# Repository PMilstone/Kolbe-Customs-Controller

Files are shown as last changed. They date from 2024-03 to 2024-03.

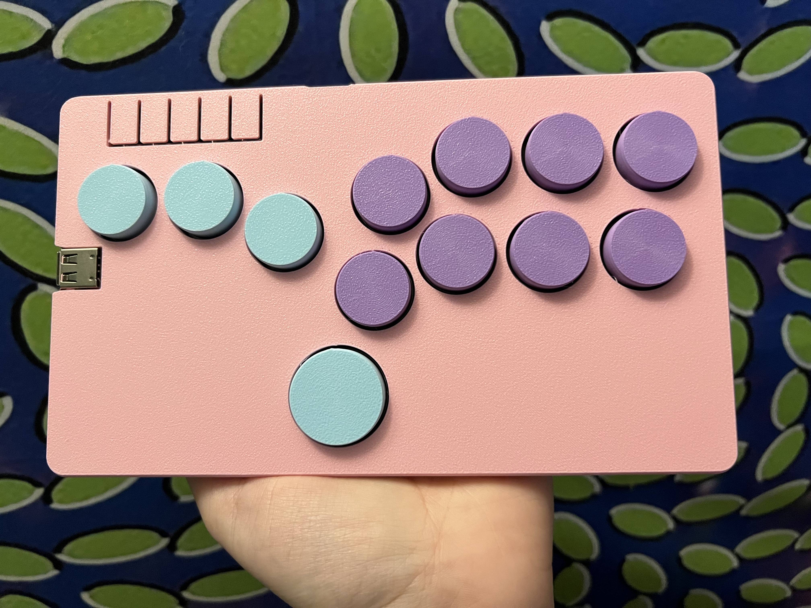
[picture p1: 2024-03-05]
Pictures/IMG_5434.jpg

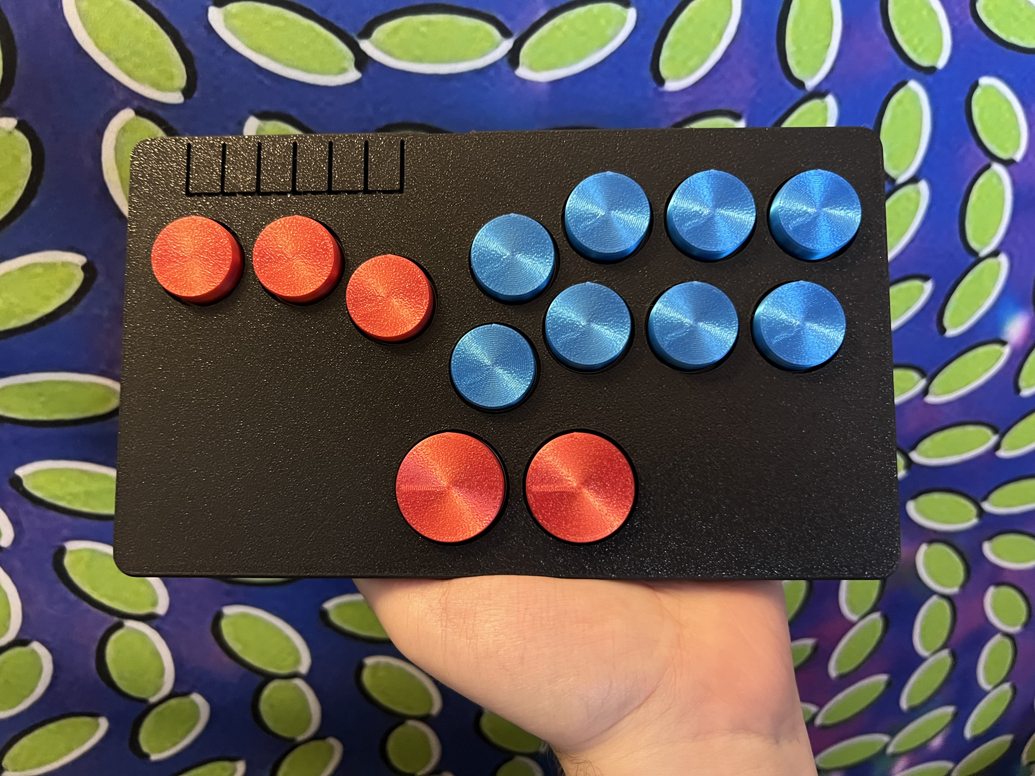
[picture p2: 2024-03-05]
Pictures/IMG_5296.jpg

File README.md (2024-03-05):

# Kolbe Customs Controller

This project is a remix of the Flatbox rev5 by jfedor2 here: https://github.com/jfedor2/flatbox/tree/master/hardware-rev5. The changes made are the following:

- Shadow lines to make a cleaner seam
- Use of M3 heat inserts
- Compatibility with Choc v2 switches

This project requires the following:

- [3D printed](3d-models) top and bottom case, 11 24mm buttons, and 1 or 2 30mm buttons
- The [PCB](pcb), with or without the USB passthrough assembely
- [RP2040-Zero](https://www.waveshare.com/rp2040-zero.htm)
- 6x [6x6x5mm tactile switches](https://www.amazon.com/gp/product/B01CGMP9GY/ref=ppx_yo_dt_b_search_asin_title?ie=UTF8&psc=1) (these come on the PCB if you buy it preassembled via jlpcb)
- Optional [USB port](https://www.mouser.com/ProductDetail/640-USB1046GF0190LBA) if using USB passthrough for Xbox S|X or PS5
- 12 or 13 [Kailh low profile (choc v2) switches](https://mechanicalkeyboards.com/shop/index.php?l=product_detail&p=6341) of your choice
- 12 or 13 [Kailh low profile hotswap sockets](https://mechanicalkeyboards.com/shop/index.php?l=product_detail&p=6995)
- 7x [M3 3.8mm heat set inserts](https://www.mcmaster.com/94180A331)
- 7x [M3 8mm Screws](https://www.mcmaster.com/91294A128) and wrench
- \(Optional)Right angle USB-C cable

Included in the 3D Models folder, there are 4 case tops. You will choose the coresponding top for if you want 2 thumb buttons, USB passthrough, or both. All options use the same bottom case.

I print my cases and buttons 0.3mm layer height with a 0.6mm nozzle.

To flash the firmware, connect the board to a computer with a USB cable, then press the RESET button while holding the BOOT button on the RP2040-Zero. A drive named "RPI-RP2" should appear. Copy the UF2 file you downloaded to that drive.

PCB design licensed under [CC BY-SA 4.0](https://creativecommons.org/licenses/by-sa/4.0/).

PCB design uses the following:

- [remix of jfedor2's flatbox rev5](https://github.com/jfedor2/flatbox/tree/master/hardware-rev5)
- [keyswitches.pretty](https://github.com/daprice/keyswitches.pretty) by [daprice](https://github.com/daprice) ([CC BY-SA 4.0](https://creativecommons.org/licenses/by-sa/4.0/))
- RP2040-Zero STEP file downloaded from [Waveshare wiki](https://www.waveshare.com/wiki/RP2040-Zero)

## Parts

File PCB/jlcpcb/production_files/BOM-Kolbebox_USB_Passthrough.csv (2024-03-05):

Comment | Designator | Footprint | LCSC
SW_Push | SW26 | SW_PUSH_6mm_H5mm
SW_Push | SW14 | SW_PUSH_6mm_H5mm
SW_Push | SW27 | SW_PUSH_6mm_H5mm
SW_Push | SW13 | SW_PUSH_6mm_H5mm
SW_Push | SW15 | SW_PUSH_6mm_H5mm
SW_Push | SW28 | SW_PUSH_6mm_H5mm
RP2040-Zero | A1 | RP2040-Zero
Fuse | F1 | Fuse_0805_2012Metric
Resistor 2 | Re2 | R_0603_1608Metric
Resistor 1 | Re1 | R_0603_1608Metric

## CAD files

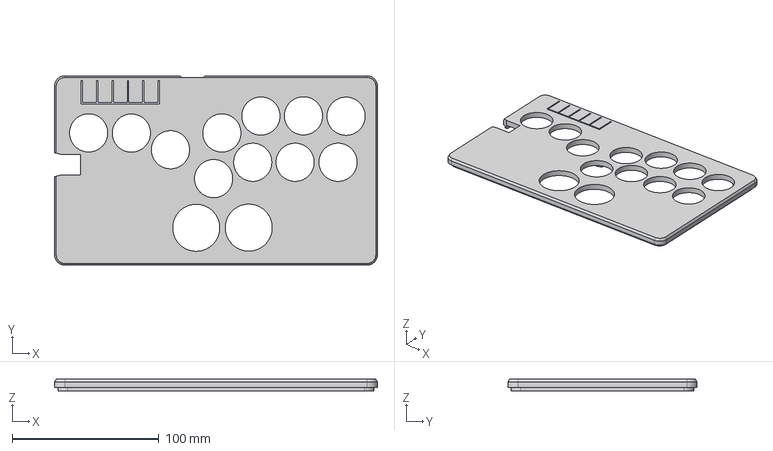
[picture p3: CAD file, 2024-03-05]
3D Models/USB Top 2 Thumb.step
219.8 x 128.7 x 8.10 mm

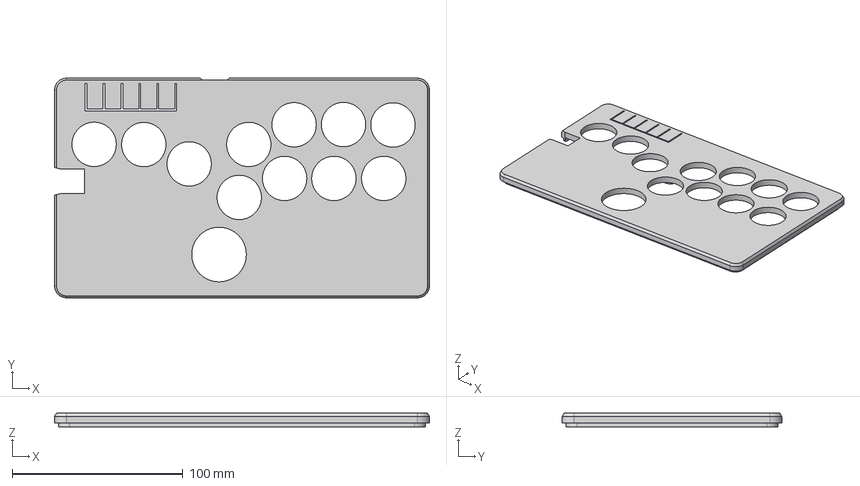
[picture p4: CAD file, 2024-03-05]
3D Models/USB Top 1 Thumb.step
219.8 x 128.7 x 8.10 mm

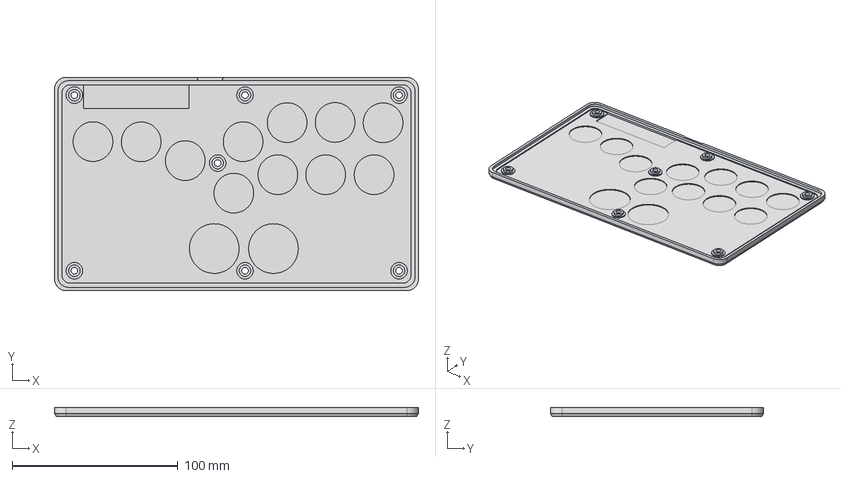
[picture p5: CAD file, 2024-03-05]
3D Models/Bottom.step
219.8 x 128.7 x 5.70 mm

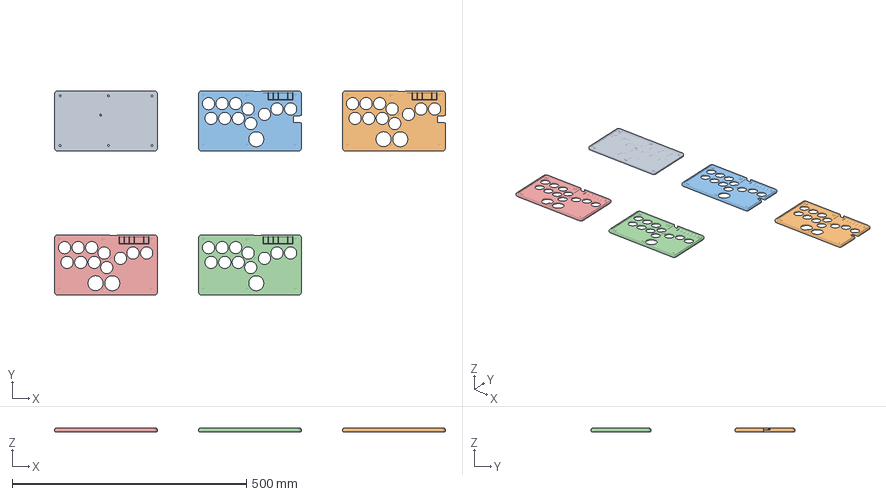
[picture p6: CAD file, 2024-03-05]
3D Models/Cases.3mf
834.2 x 435.9 x 8.10 mm
BOTTOM.step
USB TOP 2 THUMB.step
USB TOP 1 THUMB.step
Top1thumb.step
Top2Thumb.step

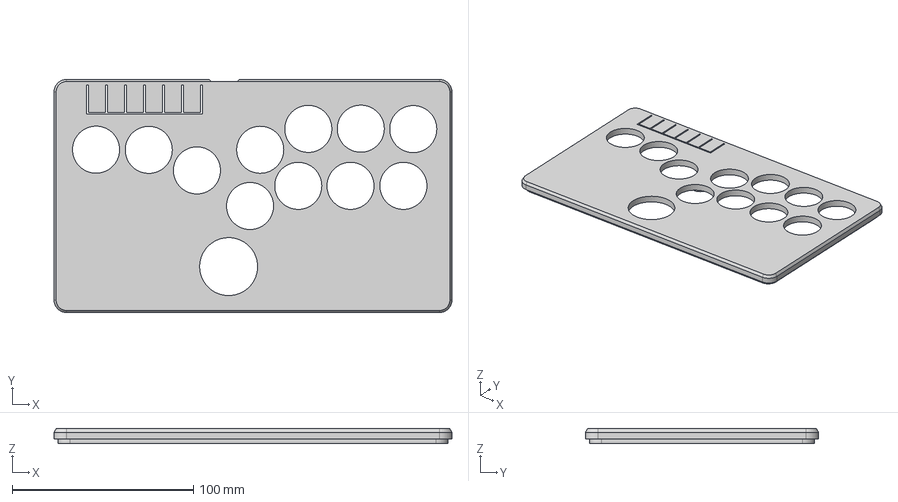
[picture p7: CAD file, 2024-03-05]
3D Models/Top 1 Thumb.step
219.8 x 128.7 x 8.10 mm

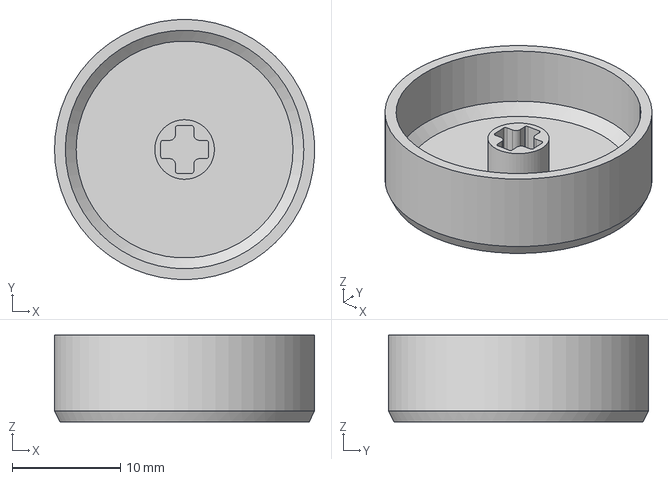
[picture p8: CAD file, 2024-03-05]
3D Models/24mm Button.step
24.0 x 24.0 x 8.00 mm

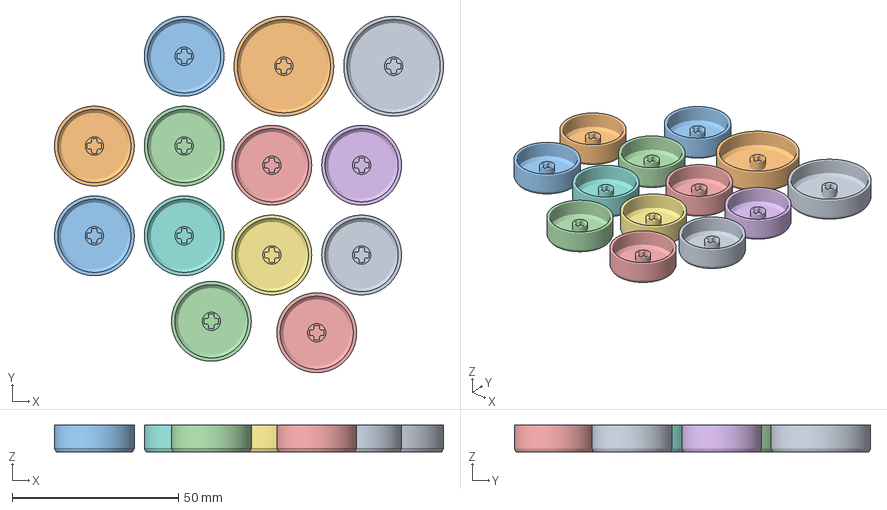
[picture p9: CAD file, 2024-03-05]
3D Models/11x24mm_2x30mm.3mf
117.0 x 107.2 x 8.00 mm
30mm Button.step x 2
24mm Button.step x 11

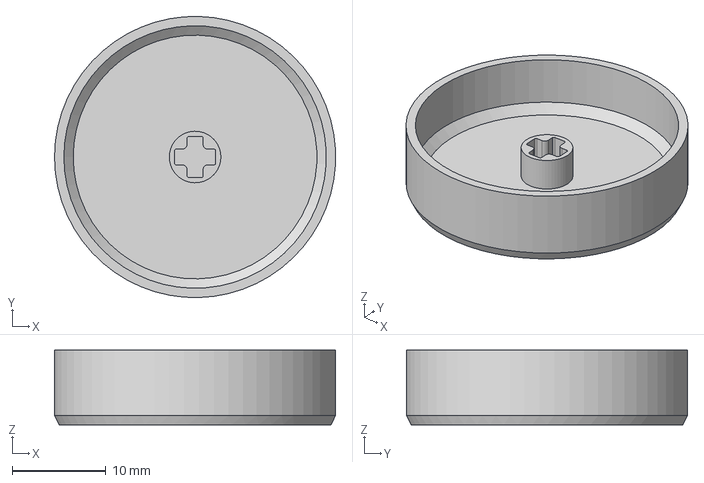
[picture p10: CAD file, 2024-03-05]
3D Models/30mm Button.step
30.0 x 30.0 x 8.00 mm

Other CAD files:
3D Models/Top 2 Thumb.step

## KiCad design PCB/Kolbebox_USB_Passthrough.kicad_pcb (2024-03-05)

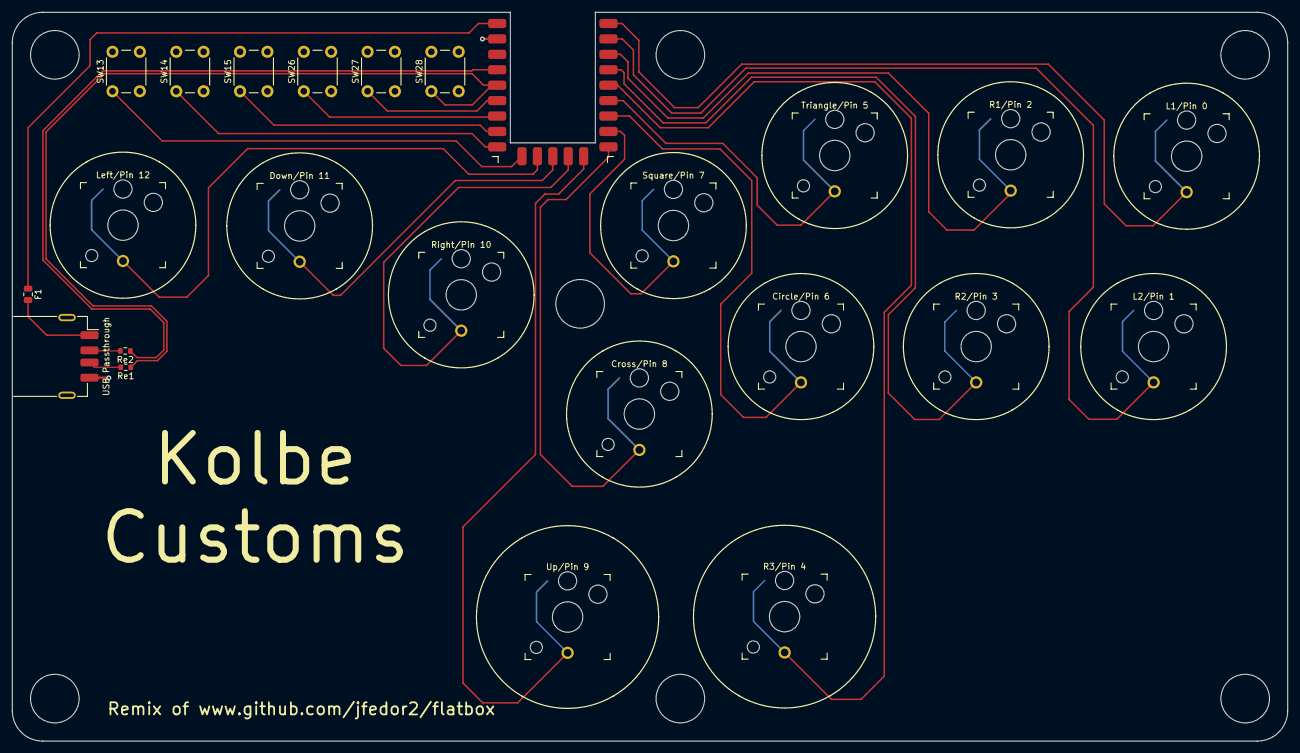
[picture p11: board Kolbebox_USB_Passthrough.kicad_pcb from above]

Board: 2 copper layers, 210.0 x 120.0 mm, 31 parts (0 on the bottom side), 22 nets.

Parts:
A1: RP2040-Zero
Circle/Pin 6: SW_Push; Kailh_socket_PG1350_optional
Cross/Pin 8: SW_Push; Kailh_socket_PG1350_optional
Down/Pin 11: SW_Push; Kailh_socket_PG1350_optional
F1: Fuse; Fuse_0805_2012Metric
H1, H2, H3, H4, H5, H6, H7: MountingHole; MountingHole_6.4mm_M6
L1/Pin 0, L2/Pin 1: SW_Push; Kailh_socket_PG1350_optional
Left/Pin 12: SW_Push; Kailh_socket_PG1350_optional
R1/Pin 2, R2/Pin 3, R3/Pin 4: SW_Push; Kailh_socket_PG1350_optional
Re1: Resistor 1; R_0603_1608Metric
Re2: Resistor 2; R_0603_1608Metric
Right/Pin 10: SW_Push; Kailh_socket_PG1350_optional
SW13, SW14, SW15, SW26, SW27, SW28: SW_Push; SW_PUSH_6mm_H5mm
Square/Pin 7: SW_Push; Kailh_socket_PG1350_optional
Triangle/Pin 5: SW_Push; Kailh_socket_PG1350_optional
USB Passthrough: USB 2.0; USB_A_Receptacle_GCT_USB1046
Up/Pin 9: SW_Push; Kailh_socket_PG1350_optional

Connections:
5V: A1.32 (5V), F1.1, F1.2, USB Passthrough.1
CIRCLE: A1.6 (GPIO6), Circle/Pin 6.1
CROSS: A1.8 (GPIO8), Cross/Pin 8.1
D+: A1.28 (GPIO28), Re1.1, Re1.2, SW28.1, USB Passthrough.3
D-: A1.29 (GPIO29), Re2.1, Re2.2, USB Passthrough.2
DOWN: A1.11 (GPIO11), Down/Pin 11.1
GND: A1.31 (GND), Circle/Pin 6.2, Cross/Pin 8.2, Down/Pin 11.2, L1/Pin 0.2, L2/Pin 1.2, Left/Pin 12.2, R1/Pin 2.2, R2/Pin 3.2, R3/Pin 4.2, Right/Pin 10.2, SW13.2, SW14.2, SW15.2, SW26.2, SW27.2, SW28.2, Square/Pin 7.2, Triangle/Pin 5.2, USB Passthrough.4, Up/Pin 9.2
L1: A1.0 (GPIO0), L1/Pin 0.1
L2: A1.1 (GPIO1), L2/Pin 1.1
LEFT: A1.12 (GPIO12), Left/Pin 12.1
OPT1: A1.13 (GPIO13), SW13.1
OPT2: A1.14 (GPIO14), SW14.1
OPT3: A1.15 (GPIO15), SW15.1
OPT4: A1.26 (GPIO26), SW26.1
OPT5: A1.27 (GPIO27), SW27.1
R1: A1.2 (GPIO2), R1/Pin 2.1
R2: A1.3 (GPIO3), R2/Pin 3.1
RIGHT: A1.10 (GPIO10), Right/Pin 10.1
SQUARE: A1.7 (GPIO7), Square/Pin 7.1
TOUCH: A1.4 (GPIO4), R3/Pin 4.1
TRIANGLE: A1.5 (GPIO5), Triangle/Pin 5.1
UP: A1.9 (GPIO9), Up/Pin 9.1
